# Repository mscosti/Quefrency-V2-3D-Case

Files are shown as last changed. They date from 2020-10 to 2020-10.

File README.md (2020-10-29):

# Quefrency V2 3D Keyboard Case
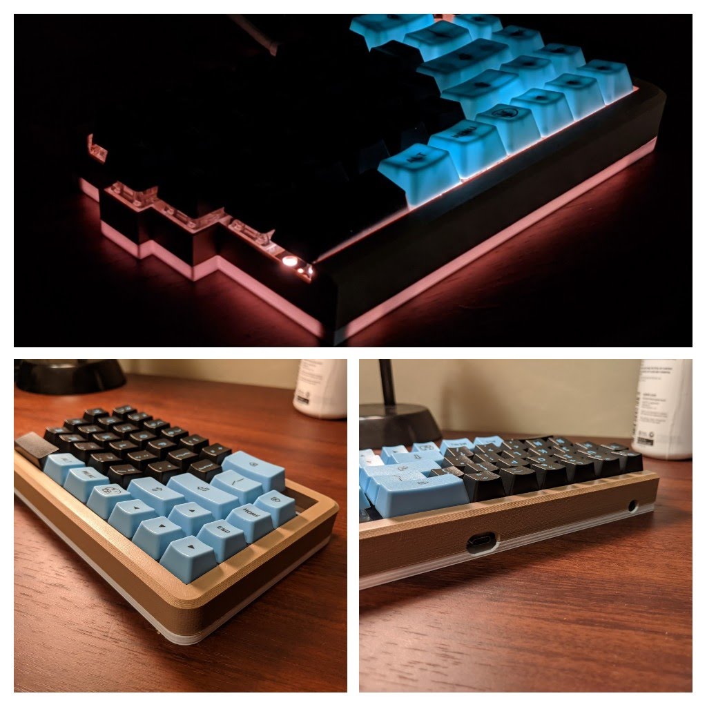
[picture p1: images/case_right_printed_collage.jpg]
Printed Right V2 case

This is a 3D printable keyboard designed for the split Quefrency V2 PCBs. Included are Fusion 360 source files, STEP files, and STLs for printing immediately.

 There are some other designs out there but none that met my personal criteria, or were closed source/paid.

## CAD Preview
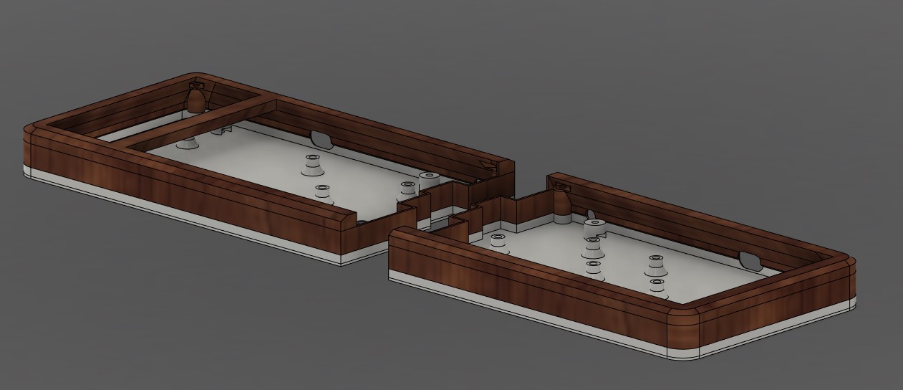
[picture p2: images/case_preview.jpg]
Fusion 360 Preview Render


## Design Goals
I designed this with a few main goals in mind.
1. The Quefrency V2 has built in RGB LEDs for underglow support, and I wanted it to be able to have that shine through the sides of the case! This means having thin sections where translucent or white filament can be used.
2. No plate is required, to simplify the design and lower costs (no need to purchase plate add ons, and makes build a little less bulky).
3. I want to have some amount of tilting/tenting support, similiar to the ergodox legs, to customize the ergonomics.

## Required Hardware
* M3x8mm screws & nuts for securing pcb to case
* Optionally, additional M3 screws/nuts of 8mm in length or higher, to allow for custimizeable tilting/tenting.

## Additional Notes
* Currently only compatible with PCB configurations of `Left with 2x5 macro pad` and `Right 65%`
  * If there is interest I can update the designs to support the `Left without macro pad` and `Right 60%` configurations.
* The case is split into 2 files for each half.
    * The PCB would be installed onto the bottom part first, and then the top part can be screwed into the bottom part.

## Still To Come / To Do
- Print settings and assembly instructions
- Reprint left case with V2 design for validation
- Print out final tilt/tent feet
- Acquire small roll of transparent PLA to see if tthat significantly improves side glow brightness or not.

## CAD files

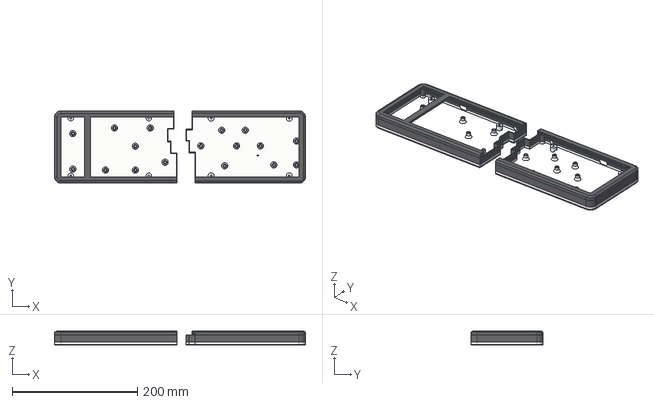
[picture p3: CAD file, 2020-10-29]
case-src/Quefrency V2 Case.step
401.5 x 115.5 x 22.5 mm
Left Case
Right Case

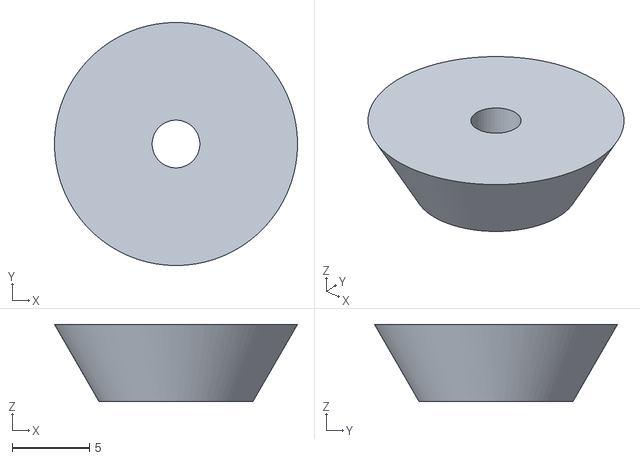
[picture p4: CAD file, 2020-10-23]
case-stls/feet/Tilt Tent Foot.stl
15.8 x 15.8 x 5.00

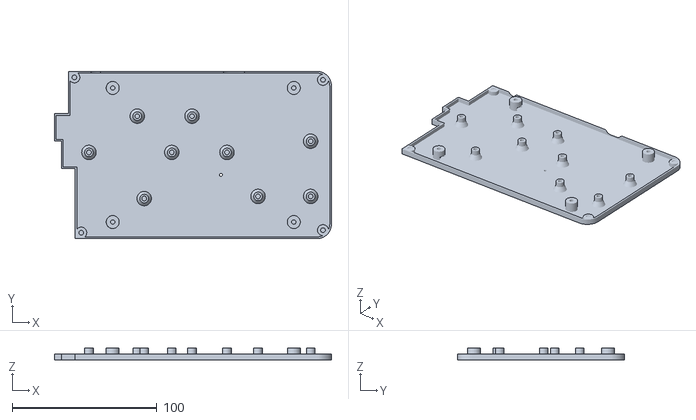
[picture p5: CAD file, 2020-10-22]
case-stls/v2/case_right_65%_bottom.stl
191.2 x 115.5 x 8.30

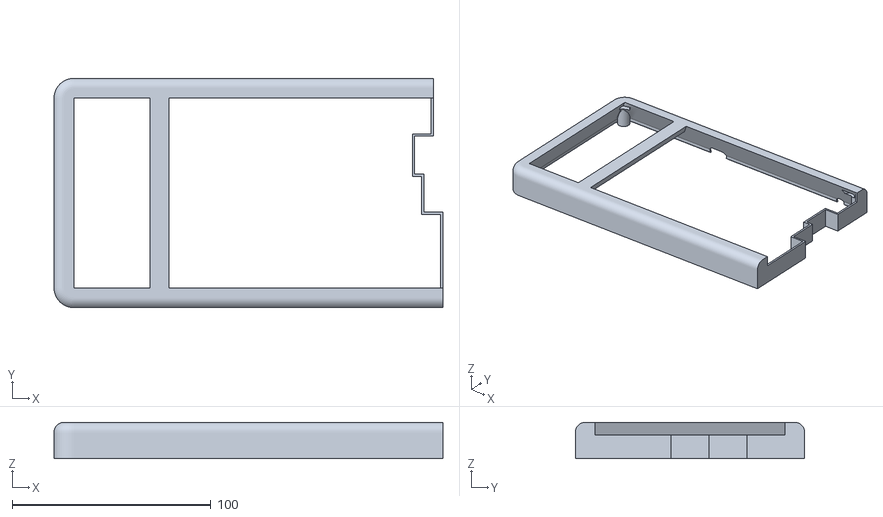
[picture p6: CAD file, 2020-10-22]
case-stls/v2/case_left_macro_top_v2.stl
195.9 x 115.5 x 18.3

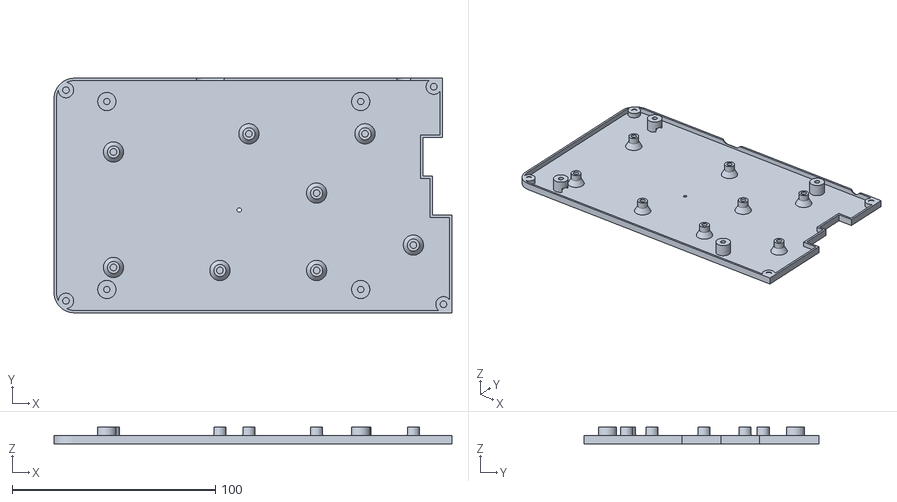
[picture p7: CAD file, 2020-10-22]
case-stls/v2/case_left_macro_bottom_v2.stl
195.9 x 115.5 x 8.30

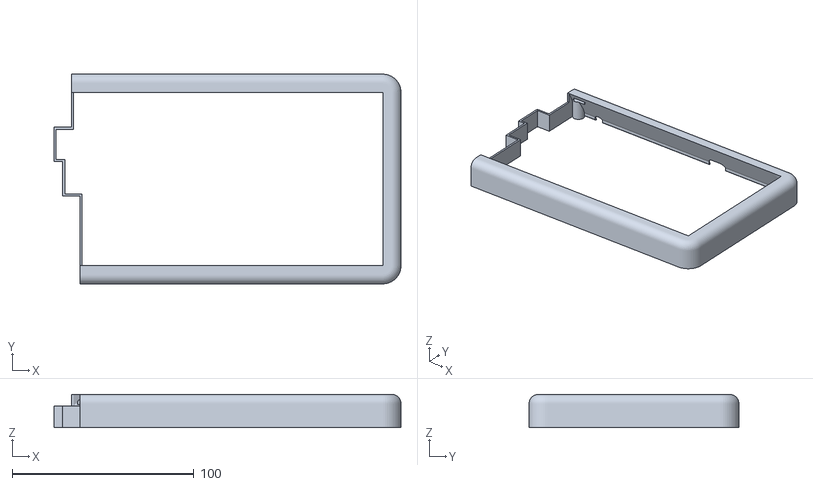
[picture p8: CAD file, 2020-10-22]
case-stls/v2/case_right_65%_top.stl
191.2 x 115.5 x 18.3

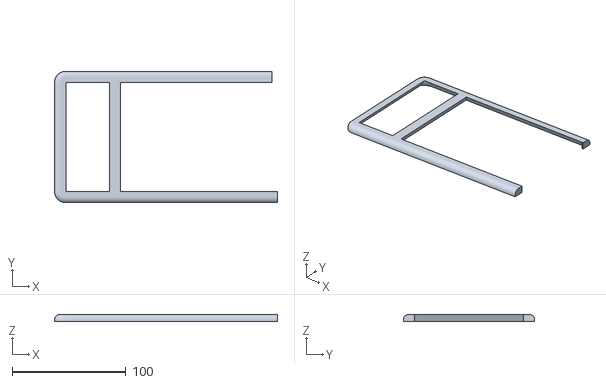
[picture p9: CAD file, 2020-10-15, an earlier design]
case-stls/v1/case_left_macro_top.stl
195.9 x 115.5 x 6.50

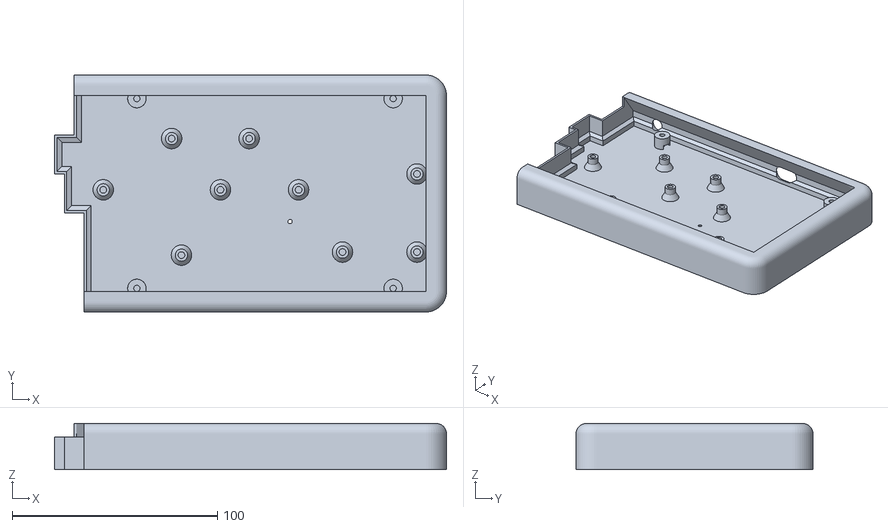
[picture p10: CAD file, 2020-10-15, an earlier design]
case-stls/v1/case_right_65%.stl
191.2 x 115.5 x 22.5

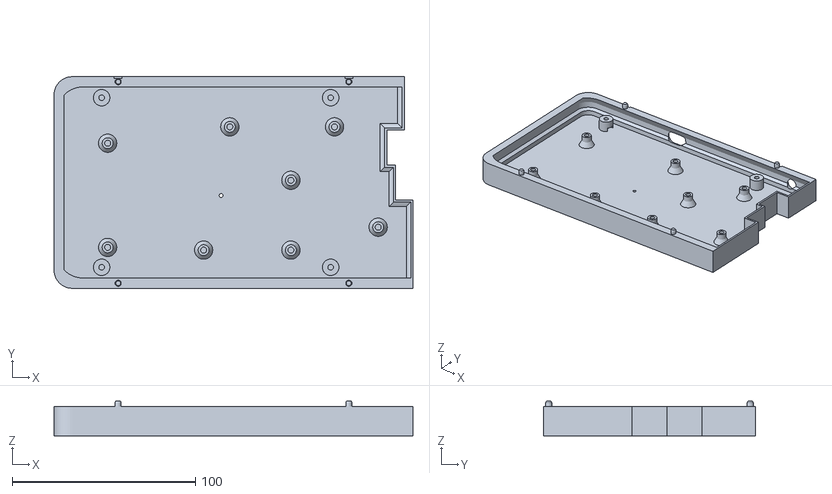
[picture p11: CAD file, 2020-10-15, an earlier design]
case-stls/v1/case_left_macro_bottom.stl
195.9 x 115.5 x 19.0

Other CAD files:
case-src/Tilt Tent Foot.step
case-src/Quefrency V2 Case.f3z
case-src/Tilt Tent Foot.f3d

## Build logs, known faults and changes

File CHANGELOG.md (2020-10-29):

# V2.2 - 10/28/2020
### Minor tolerance updates for ease of assembly
- Adjusted pcb hole size back to 3.3mm in diamter, up from 3.1mm
    - 3.1mm is too tight when screwing into a nut, makes it even harder to secure pcb
    - Left case holes as 3.1mm. Tight is ok in this situation. Instead of using captured nut, you can get away with just screwing straight into the PLA, creating threads as you go.
        - Fairly easy to change this in CAD files, or with a dremel/drill to embiggen it.
- Added small holes to back of each of the leg screw holes.
    - This makes it a lot easier to remove tightly captured nuts by poking them with a small pin.
- Top case files are now meant to be printed in the default orientation (case top is last layer)
    - removes need for difficult to remove sacrificial support layer inside the captured nut holes
    - Printing left half will require slicer supports under the macropad seperator now.
- Removed fillet around the top of the case, replaced it with a sleeker looking chamfer.

# V2.1 - 10/22/2020
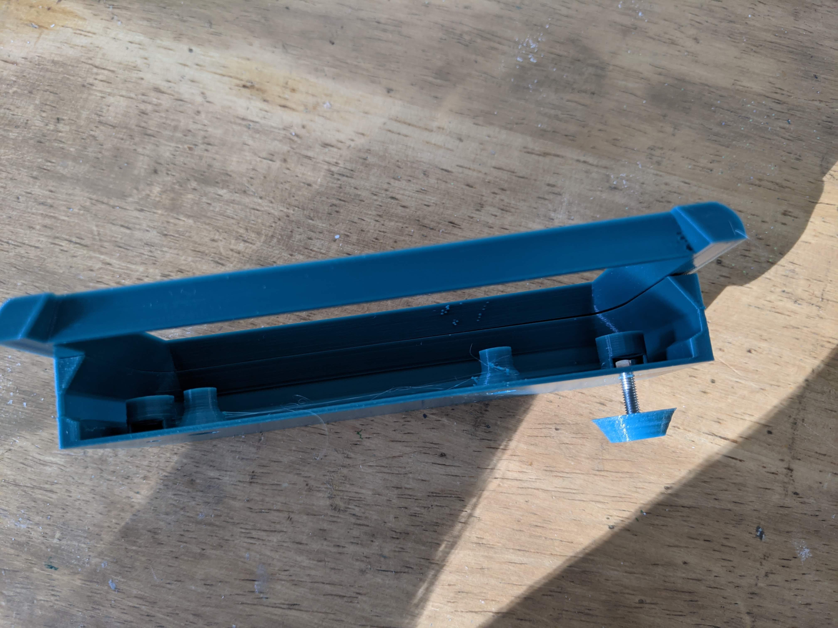
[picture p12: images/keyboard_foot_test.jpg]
Adjustable Keyboard Foot V2 Fusion Render

### Adjustable Keyboard Feet
- Added CAD and STL files for simple adjustable foot part.
- M3 screw of any length fits in tightly to cut cone piece.
- M3 nut can be inserted into up to 4 slots on each case, 2 in front, 2 in back
    - Add legs to back to get typical keyboard leg tilt
    - Add legs to front to get negative tilt
    - Add to sides to get tenting
    - Experiment with adding different length screws to each of the 4 to get the most comfortable tilt/tent angle for you.
- screw + foot can be screwed into these holes.
    - Length is variable on screw height and by how much you tighten the screw
    - Should get about ~5mm of adjustment.
- Optionally add a small rubber dome to the end for extra height and grip on desk

# V2 - 10/21/2020
V2 Fusion Render
### Case Redesign
- Redesigned so that 'light strip' is along the bottom.
    - This should make the glow along this strip much brighter; Before, the light strip began at a similiar height as the LEDS, now it is below.
- Can be printed in 2 seperate pieces now, with no filament swaps needed to achieve a 2 color case.
    - Filament swaps can be a tad annoying.
    - If you're printing in wood filament and wish to stain/paint the wood portions, it's much easier to post process the wood part now that its a seperate piece instead of a different filament on 1 part.
    - Pegs used for friction fit would snap easily, and warping could cause gaps in the case.
    - Screws together now, so whole thing should be more solid and like one piece

# V1 - 10/14/2020

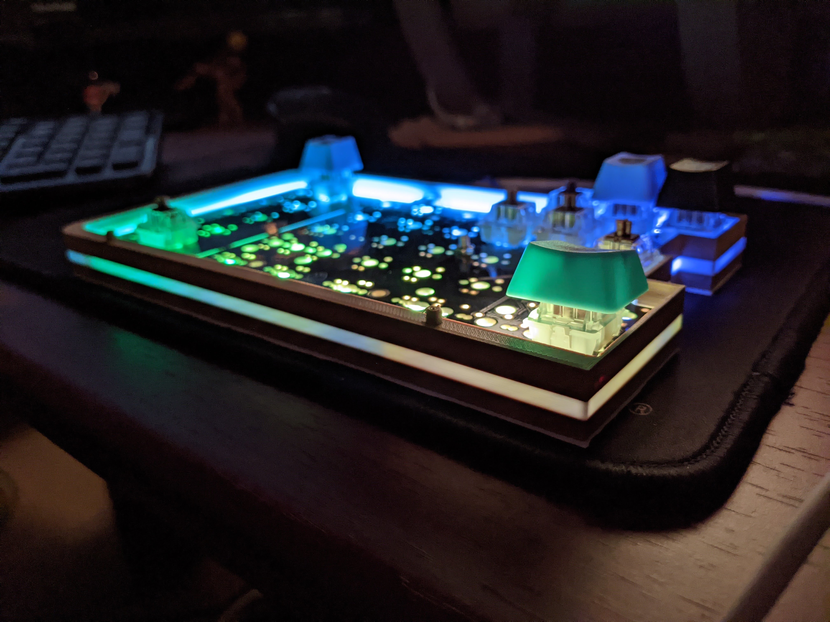
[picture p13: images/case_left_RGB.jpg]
Fusion 360 Preview Render

### Initial Release

- 'light strip' is a thin white section in the middle of the case
- Printed in 4 filament swaps
- left side of the case has top section that friction fits onto the rest of the case, after PCB installed

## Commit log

2020-10-15 Initial Release of case CAD files (#1)
    [Quefrency V2 Case.f3z, Quefrency V2 Case.step, case_left_macro_bottom.stl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]
2020-10-22 V2 design (#2)
    - 2 part case that screws together
    - light strip along bottom instead of middle
    [Quefrency V2 Case.step, case_left_macro_bottom.stl, case_left_macro_bottom_v2.stl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]
2020-10-23 V2.1 - Add adjustable Keyboard Feet (#3)
    [Tilt Tent Foot.f3d, Tilt Tent Foot.step, Tilt Tent Foot.stl]
2020-10-29 V2.2 - Added some minor convenience and tolerance changes (#4)
    [Quefrency V2 Case.step]
